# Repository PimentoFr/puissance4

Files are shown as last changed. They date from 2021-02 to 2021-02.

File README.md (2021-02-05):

# puissance4
Il s'agit d'un puissance 4 lumineux connecté et interractif par le chat Twitch

# Description

Ce projet a pour but de réaliser un écran LED basé sur des WS2812B (led addressable individuellement), piloté par un raspberry pi
afin d'ouvrir une surface de jeu pour le puissance 4. Le jeu sera connecté et intéractif avec le chat Twitch pour permettre
aux viewers et participants de chat de jouer leur partie.

Dans ce projet, l'arborescence est la suivante:
- `hardware` : L'ensemble des documents permettant la réalisation des cartes électroniques du projet
    - `panneau_led`: Contient le design de la carte électronique des dalles de LEDs.
    - `mainboard`: Carte principale permettant l'alimentation des Bucks 24V-5V pour les colonnes de la matrice de LEDs et la connection
    du Raspberry Pi.
- `software` : Bientôt.

# Logiciels

Les logiciels utilisées sont les suivants:
- hardware : [Kicad](https://kicad.org/download/)

# Electronique

## Panneau led

Les panneaux LEDs sont des panneaux de 90x90mm qui accueille chacun 9 LEDs de type WS2812B.
Elles sont tous chaînés de la manière suivante:

```
1 -> 2 -> 3
 <--------|
4 -> 5 -> 6
 <--------|
7 -> 8 -> 9
```

## Mainboard

Cette carte permet d'accueillir la source d'alimentation (Prise Power Jack 24V 4A) et de la répartir sur 7 borniers afin d'y brancher 7 convertisseurs DC/DC Buck pour alimenter chacun des 7 colonnes de la matrice de LEDs.
A cela, un support femelle 2x20 pins permet de connnecter un
Raspberry Pi afin d'assurer l'intelligence et le pilotage de ce
panneau LEDs. Un level shifter 3.3V->5V permet d'assurer l'adaptation de niveau logique entre la commande émise par le
Raspberry Pi et les WS2812B.

Plusieurs connecteurs supplémentaires permettent de brancher
d'autres périphériques au besoin en I2C/SPI/UART.

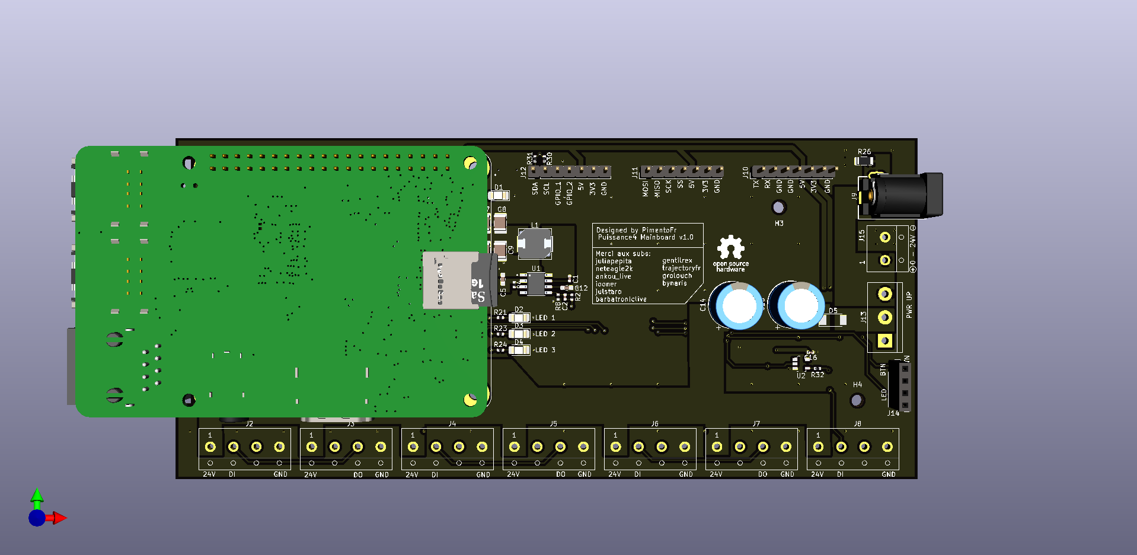
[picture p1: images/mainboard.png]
Mainboard

# Licence

Le projet est open-source. Tout le monde peut l'utiliser en laissant la référence à son auteur.

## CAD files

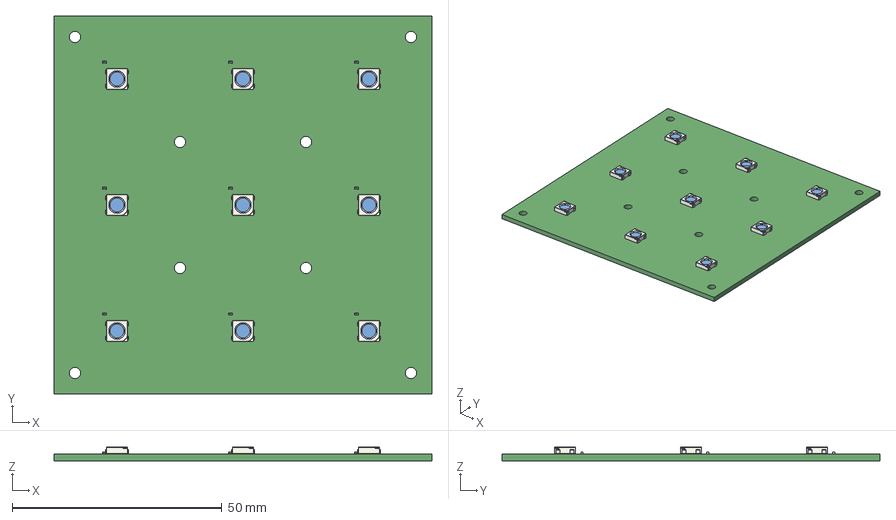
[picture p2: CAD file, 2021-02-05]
hardware/panneau_led/panneau led.step
90.0 x 90.0 x 3.25 mm

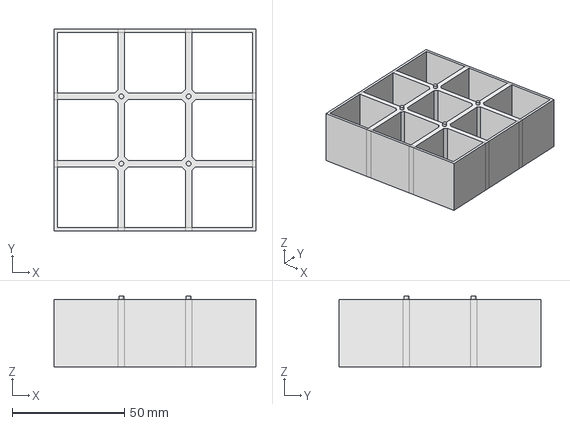
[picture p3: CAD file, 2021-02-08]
mecanics/separator_led.FCStd
90.0 x 90.0 x 31.6 mm

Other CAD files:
mecanics/separator_led.stl

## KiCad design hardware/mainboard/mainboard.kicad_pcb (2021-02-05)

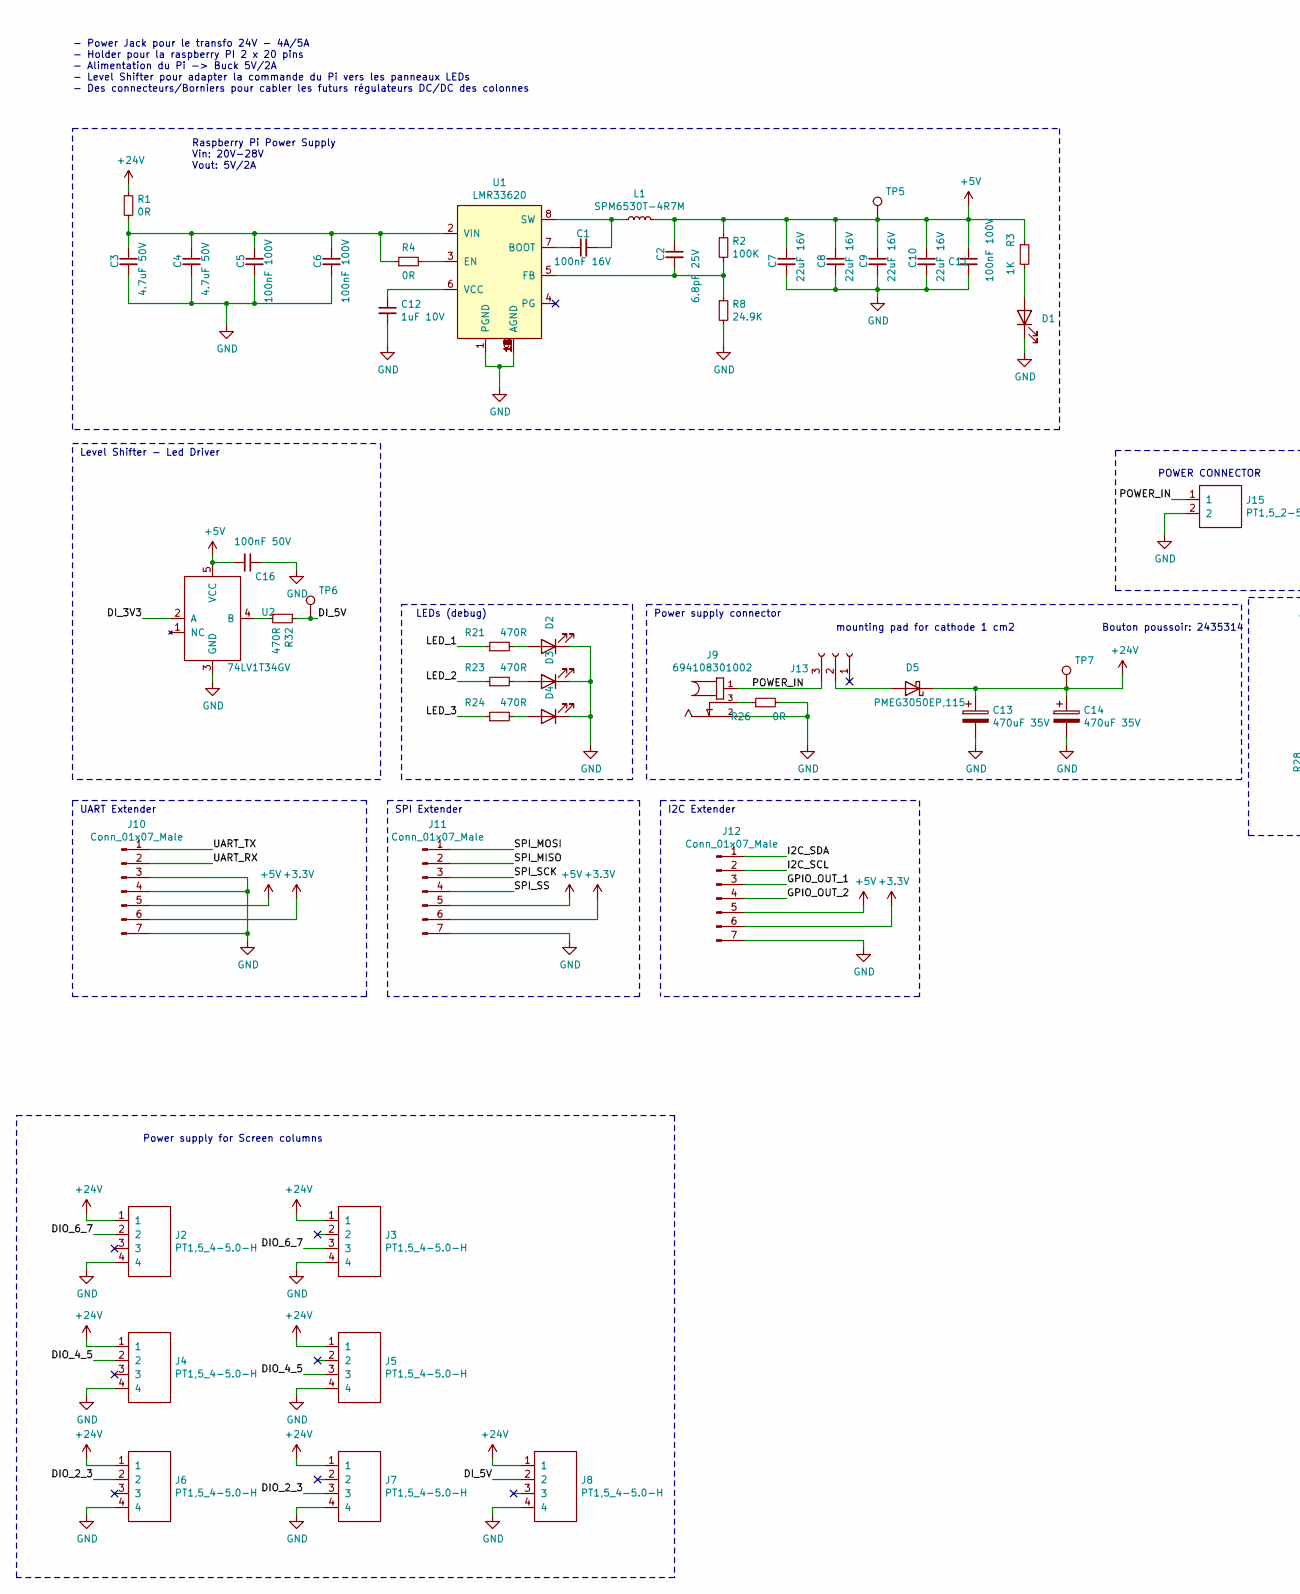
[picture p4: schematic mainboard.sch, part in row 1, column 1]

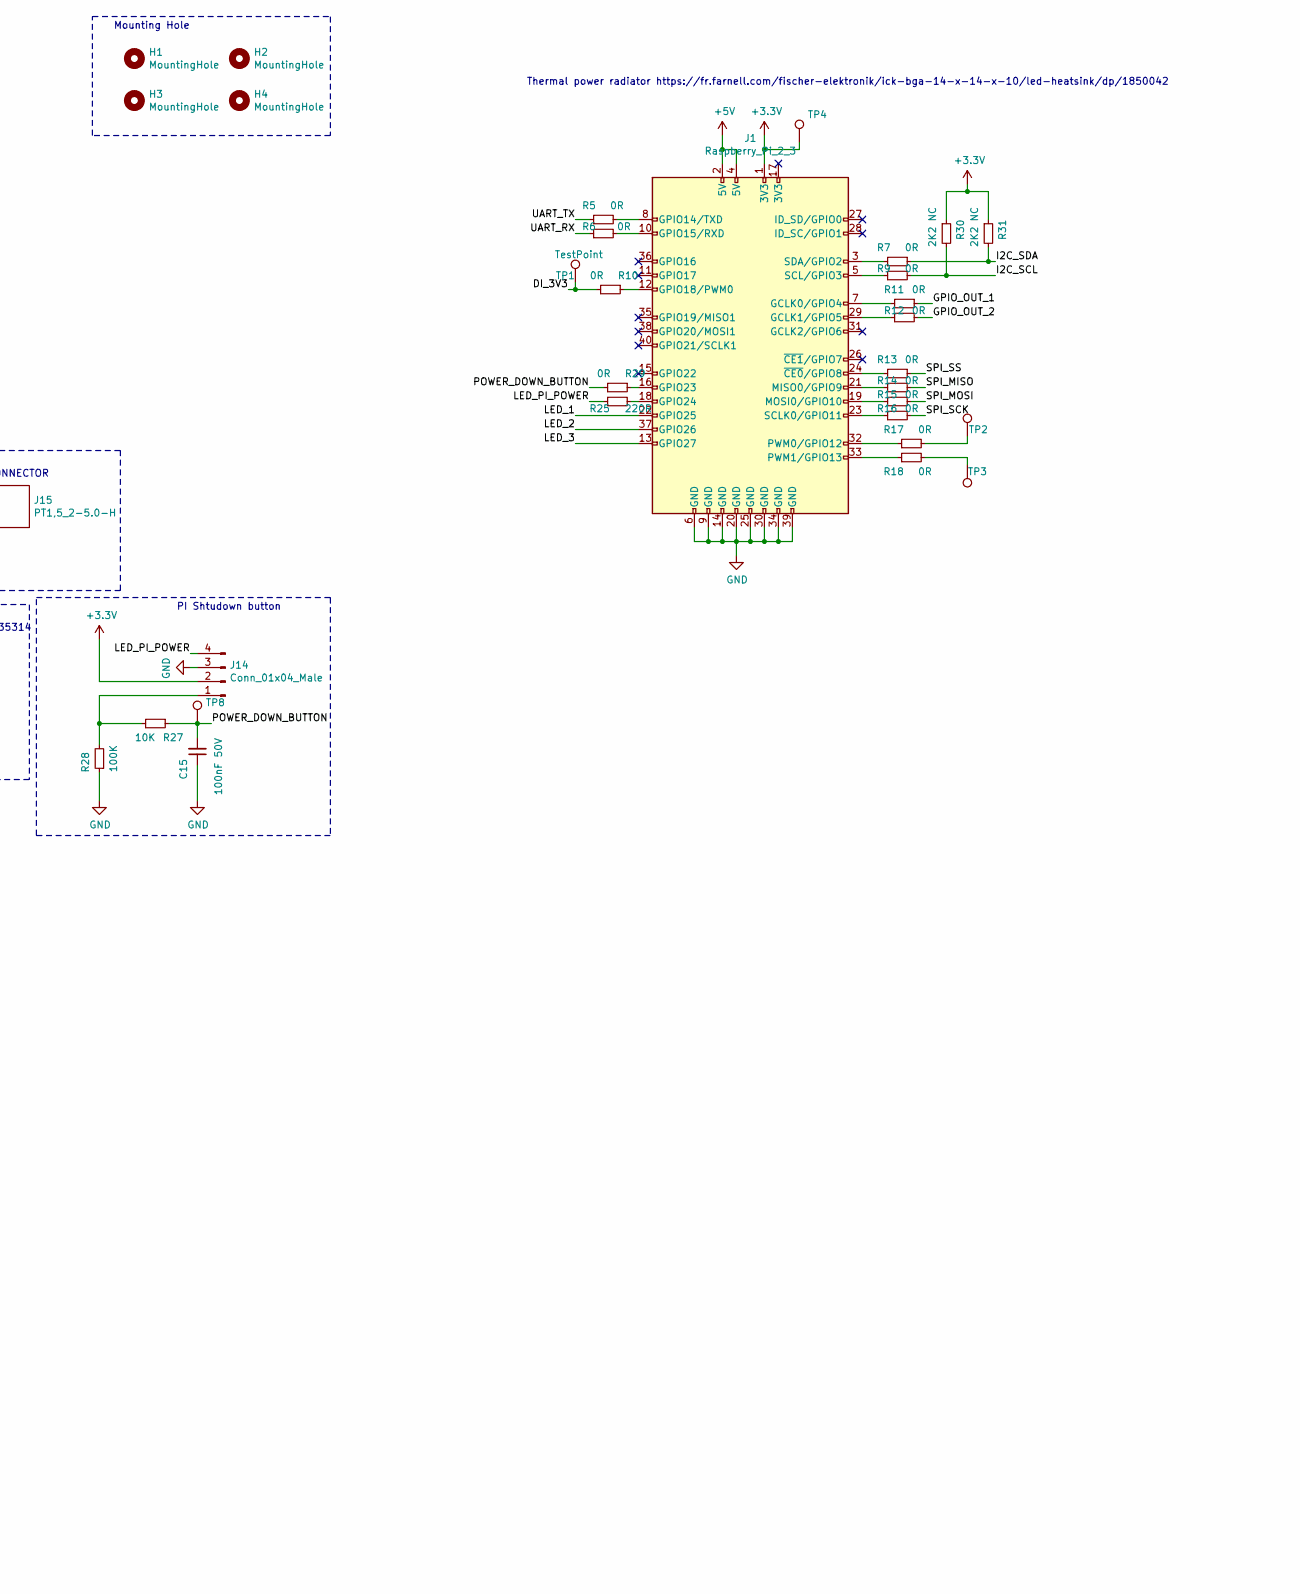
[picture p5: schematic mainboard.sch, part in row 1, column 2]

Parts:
C1: 100nF 16V; C_0402_1005Metric; farnell 2627345
C2: 6.8pF 25V; C_0402_1005Metric; farnell 2781440
C3: 4.7uF 50V; C_1206_3216Metric_Pad1.42x1.75mm_HandSolder; farnell 1735545
C4: 4.7uF 50V; C_1206_3216Metric_Pad1.42x1.75mm_HandSolder
C5, C6, C11: 100nF 100V; C_0603_1608Metric_Pad1.05x0.95mm_HandSolder; farnell 1828921
C7, C8, C9, C10: 22uF 16V; C_1210_3225Metric_Pad1.42x2.65mm_HandSolder; farnell 2112725
C12: 1uF 10V; C_0603_1608Metric_Pad1.05x0.95mm_HandSolder; farnell 9227776
C13, C14: 470uF 35V; CP_Radial_D10.0mm_P5.00mm; farnell 2805546
C15, C16: 100nF 50V; C_0402_1005Metric
D1, D2, D3, D4: MCL-S250GC; LED_1206_3216Metric_Pad1.42x1.75mm_HandSolder; farnell 1581232
D5: PMEG3050EP,115; D_SOD-128; farnell 1829197
H1, H2, H3, H4: MountingHole; MountingHole_2.5mm
J1: Raspberry_Pi_2_3; MODULE_RASPBERRY_PI_3_MODEL_B+_REVERSE
J2, J3, J4, J5, J6, J7, J8: PT1,5_4-5.0-H; PT1,5-4-5.0-H; farnell 1793677
J9: 694108301002; PART-NUMBER 694108301002; farnell 2472153
J10, J11: Conn_01x07_Male; PinHeader_1x07_P2.54mm_Vertical
J12: Conn_01x07_Male; PinHeader_1x07_P2.54mm_Vertical; farnell 2847167
J13: Conn_01x03_Female; TerminalBlock_bornier-3_P5.08mm
J14: Conn_01x04_Male; PinSocket_1x04_P2.54mm_Vertical
J15: PT1,5_2-5.0-H; PT1,5-2-5.0-H
L1: SPM6530T-4R7M; SPM6530T; farnell 2215613
R1: 0R; R_0805_2012Metric_Pad1.15x1.40mm_HandSolder
R2, R28: 100K; R_0402_1005Metric
R3: 1K; R_0402_1005Metric
R4, R5, R6, R7, R9, R10, R11, R12, R13, R14, R15, R16, R17, R18, R29: 0R; R_0402_1005Metric
R8: 24.9K; R_0402_1005Metric
R21, R23, R24, R32: 470R; R_0402_1005Metric
R25: 220R; R_0402_1005Metric
R26: 0R; R_1206_3216Metric
R27: 10K; R_0402_1005Metric
R30, R31: 2K2 NC; R_0402_1005Metric
TP1, TP2, TP3, TP4, TP5, TP6, TP7, TP8: TestPoint; TestPoint_Pad_D1.0mm
U1: LMR33620; 8pin-HSOIC; farnell 3007264
U2: 74LV1T34GV; SOT-753; farnell 3485601

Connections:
+3V3: J1.1 (3V3), J10.6, J11.6, J12.6, J14.2, R30.1, R31.1, TP4.1
+5V: C2.1, C7.1, C8.1, C9.1, C10.1, C11.1, C16.2, J1.2 (5V), J1.4 (5V), J10.5, J11.5, J12.5, L1.2, R2.1, R3.1, TP5.1, U2.5 (VCC)
+24V: C13.1, C14.1, D5.1 (K), J2.1, J3.1, J4.1, J5.1, J6.1, J7.1, J8.1, R1.1, TP7.1
/DIO_2_3: J6.2, J7.3
/DIO_4_5: J4.2, J5.3
/DIO_6_7: J2.2, J3.3
/DI_3V3: R10.2, TP1.1, U2.2 (A)
/DI_5V: J8.2, R32.1, TP6.1
/GPIO_OUT_1: J12.3, R11.1
/GPIO_OUT_2: J12.4, R12.1
/I2C_SCL: J12.2, R9.1, R30.2
/I2C_SDA: J12.1, R7.1, R31.2
/LED_1: J1.22 (GPIO25), R21.1
/LED_2: J1.37 (GPIO26), R23.1
/LED_3: J1.13 (GPIO27), R24.1
/LED_PI_POWER: J14.4, R25.1
/POWER_DOWN_BUTTON: C15.2, R27.1, R29.2, TP8.1
/POWER_IN: J9.1, J13.3, J15.1
/SPI_MISO: J11.2, R14.1
/SPI_MOSI: J11.1, R15.1
/SPI_SCK: J11.3, R16.1
/SPI_SS: J11.4, R13.1
/UART_RX: J10.2, R6.1
/UART_TX: J10.1, R5.1
GND: C3.2, C4.2, C5.2, C6.2, C7.2, C8.2, C9.2, C10.2, C11.2, C12.2, C13.2, C14.2, C15.1, C16.1, D1.1 (K), D2.1 (K), D3.1 (K), D4.1 (K), J1.6 (GND), J1.9 (GND), J1.14 (GND), J1.20 (GND), J1.25 (GND), J1.30 (GND), J1.34 (GND), J1.39 (GND), J2.4, J3.4, J4.4, J5.4, J6.4, J7.4, J8.4, J9.2, J10.3, J10.4, J10.7, J11.7, J12.7, J14.3, J15.2, R8.2, R26.2, R28.1, U1.1 (PGND), U1.9 (AGND), U1.10 (AGND), U1.11 (AGND), U1.12 (AGND), U1.13 (AGND), U1.14 (AGND), U1.15 (AGND), U1.16 (AGND), U1.17 (AGND), U2.3 (GND)
unnamed: C1.1, U1.7 (BOOT)
unnamed: C1.2, L1.1, U1.8 (SW)
unnamed: C2.2, R2.2, R8.1, U1.5 (FB)
unnamed: C3.1, C4.1, C5.1, C6.1, R1.2, R4.1, U1.2 (VIN)
unnamed: C12.1, U1.6 (VCC)
unnamed: D1.2 (A), R3.2
unnamed: D2.2 (A), R21.2
unnamed: D3.2 (A), R23.2
unnamed: D4.2 (A), R24.2
unnamed: D5.2 (A), J13.2
unnamed: J1.3 (SDA/GPIO2), R7.2
unnamed: J1.5 (SCL/GPIO3), R9.2
unnamed: J1.7 (GCLK0/GPIO4), R11.2
unnamed: J1.8 (GPIO14/TXD), R5.2
unnamed: J1.10 (GPIO15/RXD), R6.2
unnamed: J1.12 (GPIO18/PWM0), R10.1
unnamed: J1.16 (GPIO23), R29.1
unnamed: J1.18 (GPIO24), R25.2
unnamed: J1.19 (MOSI0/GPIO10), R15.2
unnamed: J1.21 (MISO0/GPIO9), R14.2
unnamed: J1.23 (SCLK0/GPIO11), R16.2
unnamed: J1.24 (~CE0~/GPIO8), R13.2
unnamed: J1.29 (GCLK1/GPIO5), R12.2
unnamed: J1.32 (PWM0/GPIO12), R17.1
unnamed: J1.33 (PWM1/GPIO13), R18.1
unnamed: J9.3, R26.1
unnamed: J14.1, R27.2, R28.2
unnamed: R4.2, U1.3 (EN)
unnamed: R17.2, TP2.1
unnamed: R18.2, TP3.1
unnamed: R32.2, U2.4 (B)

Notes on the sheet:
- Power Jack pour le transfo 24V - 4A/5A - Holder pour la raspberry PI 2 x 20 pins - Alimentation du Pi -> Buck 5V/2A - Level Shifter pour adapter la commande du Pi vers les panneaux LEDs - Des connecteurs/Borniers pour cabler les futurs régulateurs DC/DC des colonnes
Raspberry Pi Power Supply Vin: 20V-28V Vout: 5V/2A
Power supply connector
Level Shifter - Led Driver
Power supply for Screen columns
LEDs (debug)
UART Extender
SPI Extender
I2C Extender
mounting pad for cathode 1 cm2
Bouton poussoir: 2435314
POWER CONNECTOR
PI Shtudown button
Mounting Hole
Thermal power radiator https://fr.farnell.com/fischer-elektronik/ick-bga-14-x-14-x-10/led-heatsink/dp/1850042

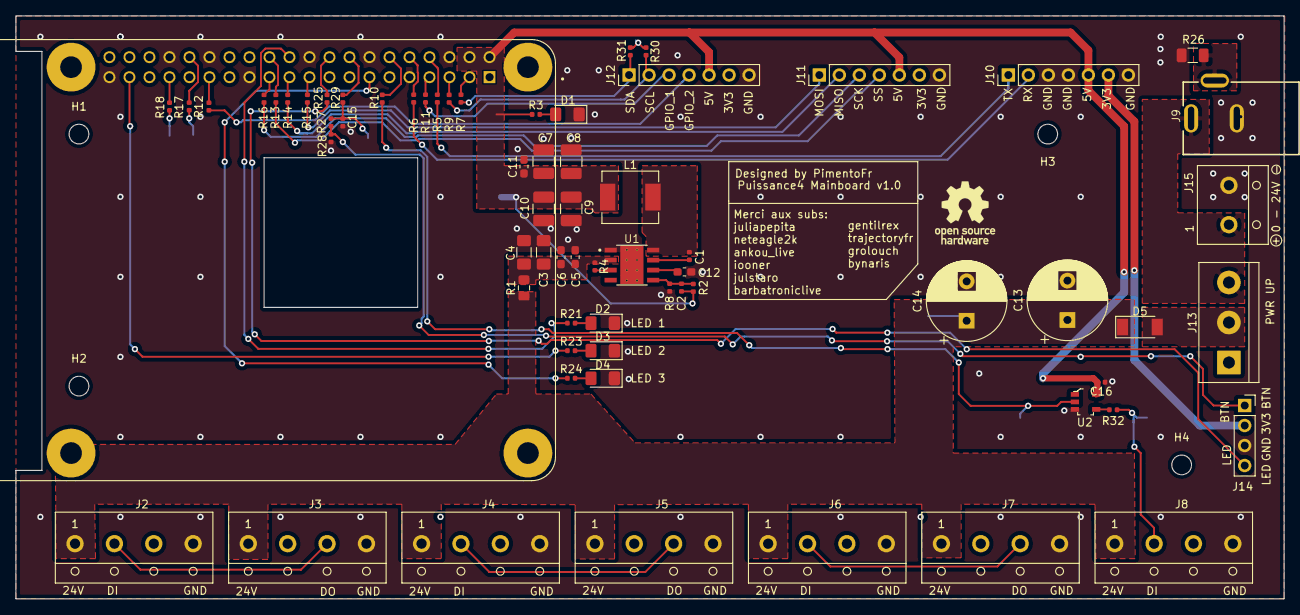
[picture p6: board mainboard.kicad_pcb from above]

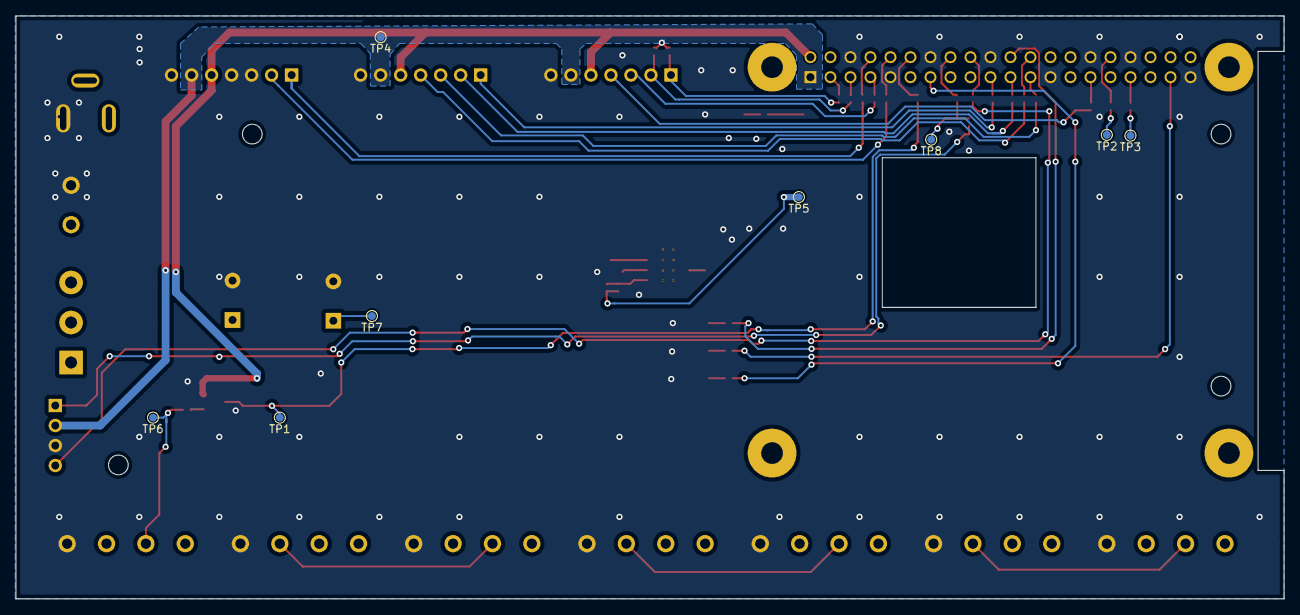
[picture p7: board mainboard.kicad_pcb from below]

Board: 2 copper layers, 161.0 x 74.0 mm, 80 parts (8 on the bottom side), 56 nets.

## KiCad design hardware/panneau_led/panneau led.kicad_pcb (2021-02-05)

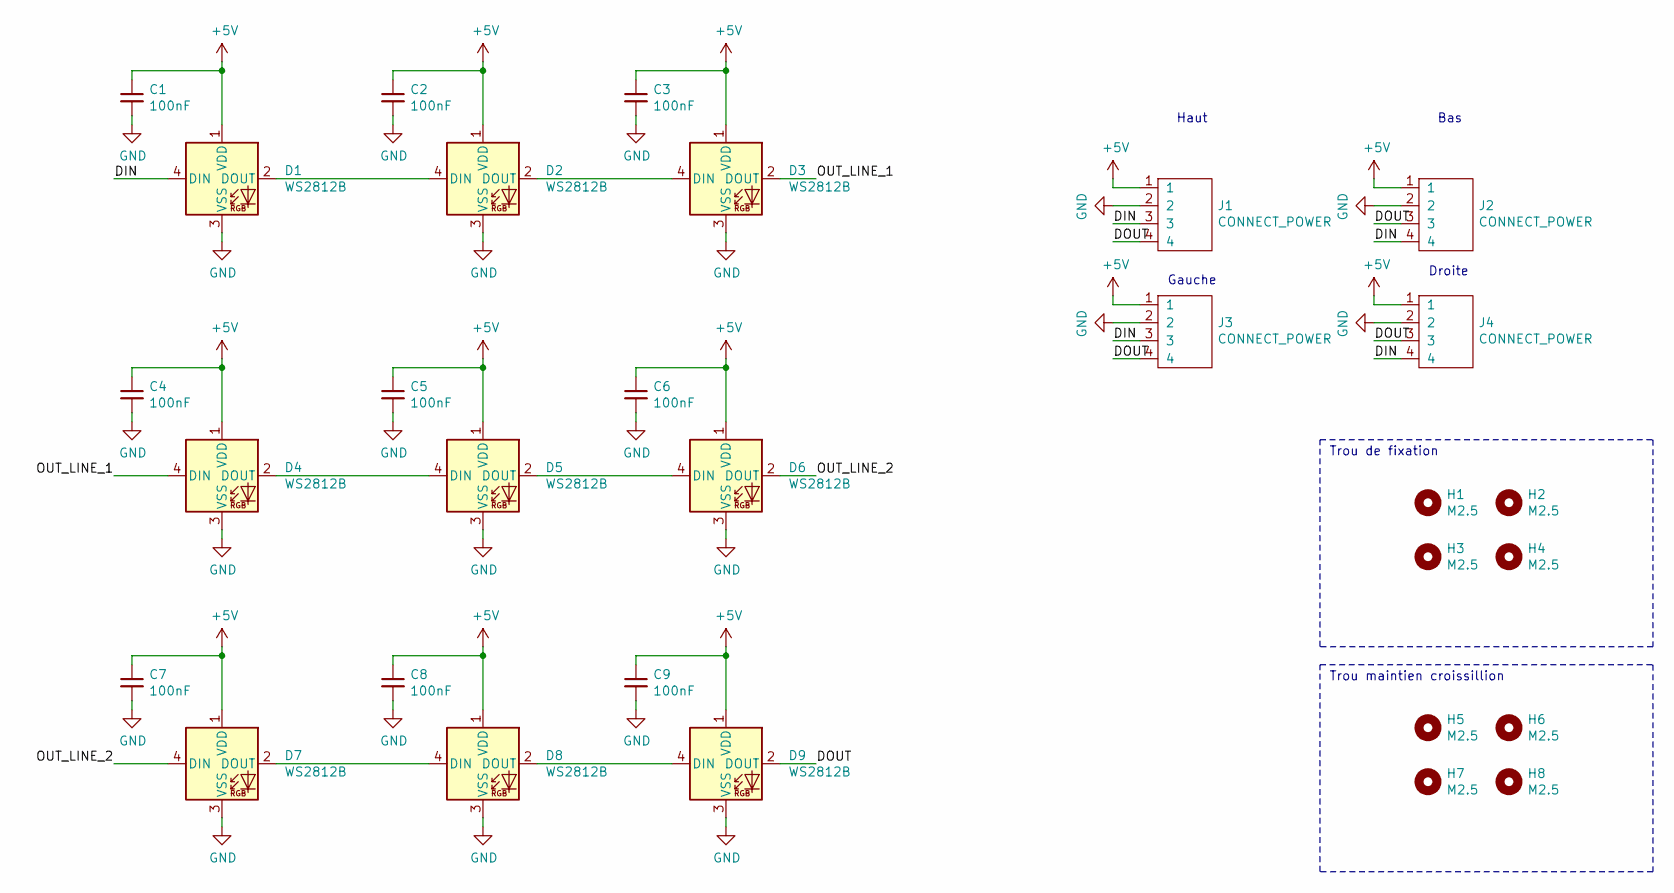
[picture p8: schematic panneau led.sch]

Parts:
C1, C2, C3, C4, C5, C6, C7, C8, C9: 100nF; C_0402_1005Metric; lcsc C1525
D1, D2, D3, D4, D5, D6, D7, D8, D9: WS2812B; LED_WS2812B_PLCC4_5.0x5.0mm_P3.2mm; lcsc C114586
H1, H2, H3, H4, H5, H6, H7, H8: M2.5; MountingHole_2.7mm_M2.5; lcsc NA
J1, J2, J3, J4: CONNECT_POWER; lcsc NA

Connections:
+5V: C1.1, C2.1, C3.1, C4.1, C5.1, C6.1, C7.1, C8.1, C9.1, D1.1 (VDD), D2.1 (VDD), D3.1 (VDD), D4.1 (VDD), D5.1 (VDD), D6.1 (VDD), D7.1 (VDD), D8.1 (VDD), D9.1 (VDD), J1.1, J2.1, J3.1, J4.1
/DIN: D1.4 (DIN), J1.3, J2.4, J3.3, J4.4
/DOUT: D9.2 (DOUT), J1.4, J2.3, J3.4, J4.3
/OUT_LINE_1: D3.2 (DOUT), D4.4 (DIN)
/OUT_LINE_2: D6.2 (DOUT), D7.4 (DIN)
GND: C1.2, C2.2, C3.2, C4.2, C5.2, C6.2, C7.2, C8.2, C9.2, D1.3 (VSS), D2.3 (VSS), D3.3 (VSS), D4.3 (VSS), D5.3 (VSS), D6.3 (VSS), D7.3 (VSS), D8.3 (VSS), D9.3 (VSS), J1.2, J2.2, J3.2, J4.2
unnamed: D1.2 (DOUT), D2.4 (DIN)
unnamed: D2.2 (DOUT), D3.4 (DIN)
unnamed: D4.2 (DOUT), D5.4 (DIN)
unnamed: D5.2 (DOUT), D6.4 (DIN)
unnamed: D7.2 (DOUT), D8.4 (DIN)
unnamed: D8.2 (DOUT), D9.4 (DIN)

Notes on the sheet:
Haut
Bas
Gauche
Droite
Trou de fixation
Trou maintien croissillion

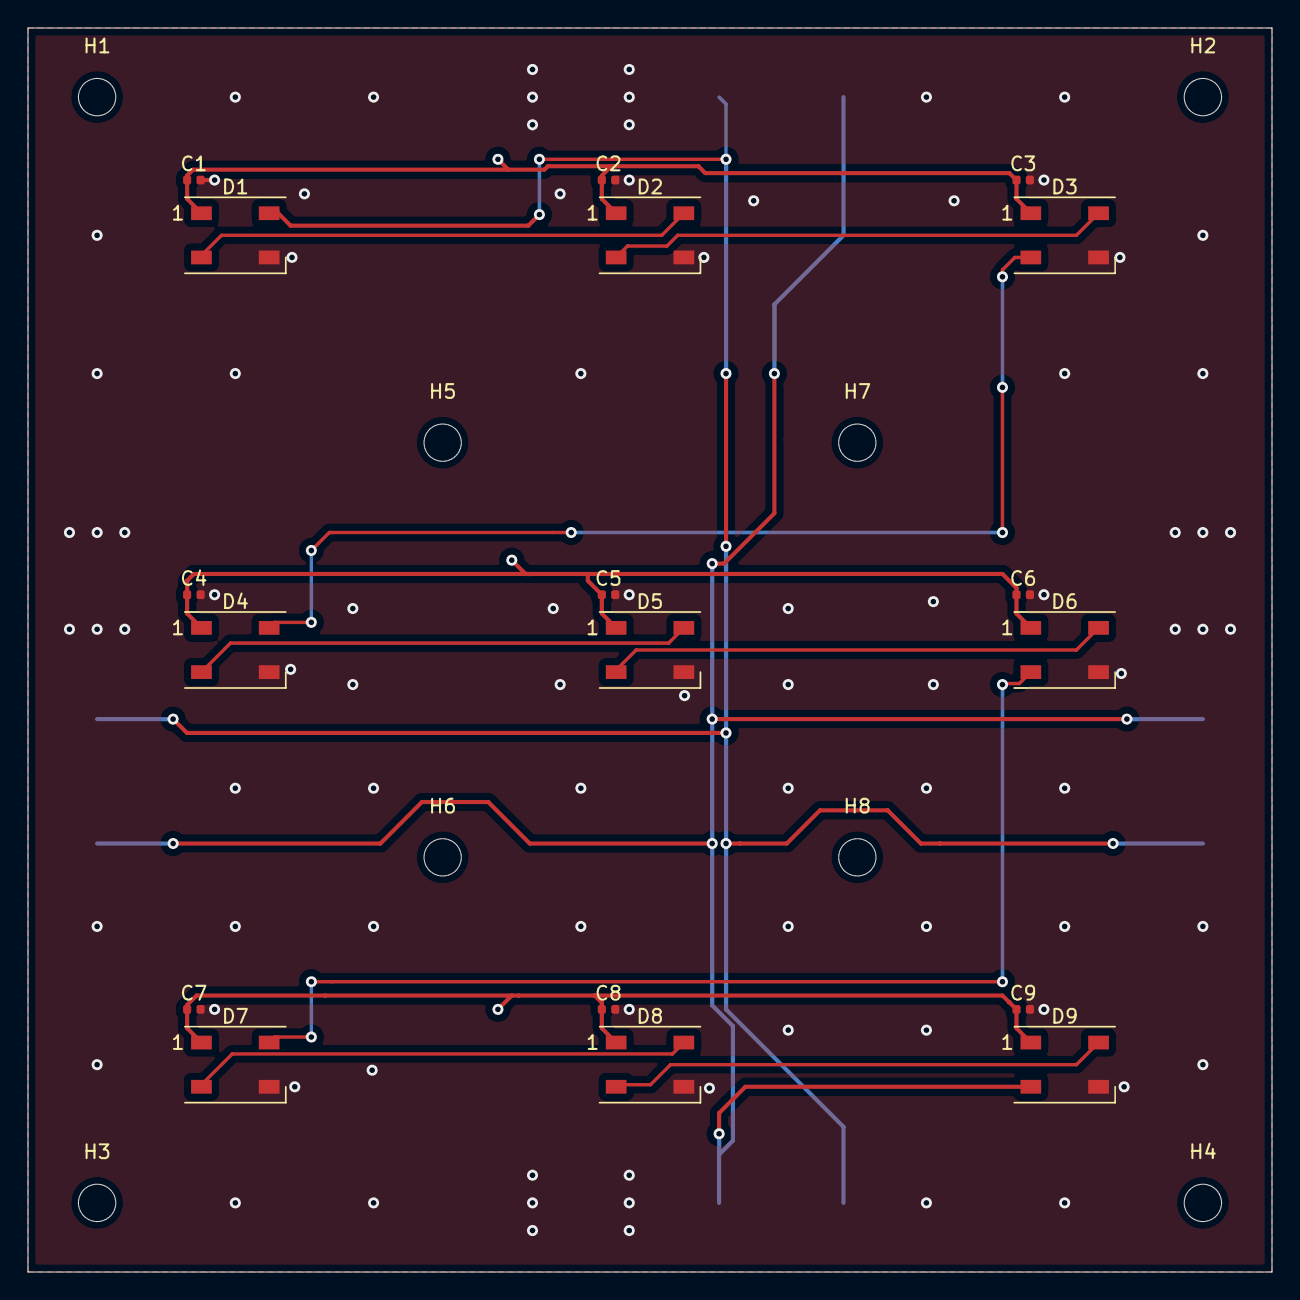
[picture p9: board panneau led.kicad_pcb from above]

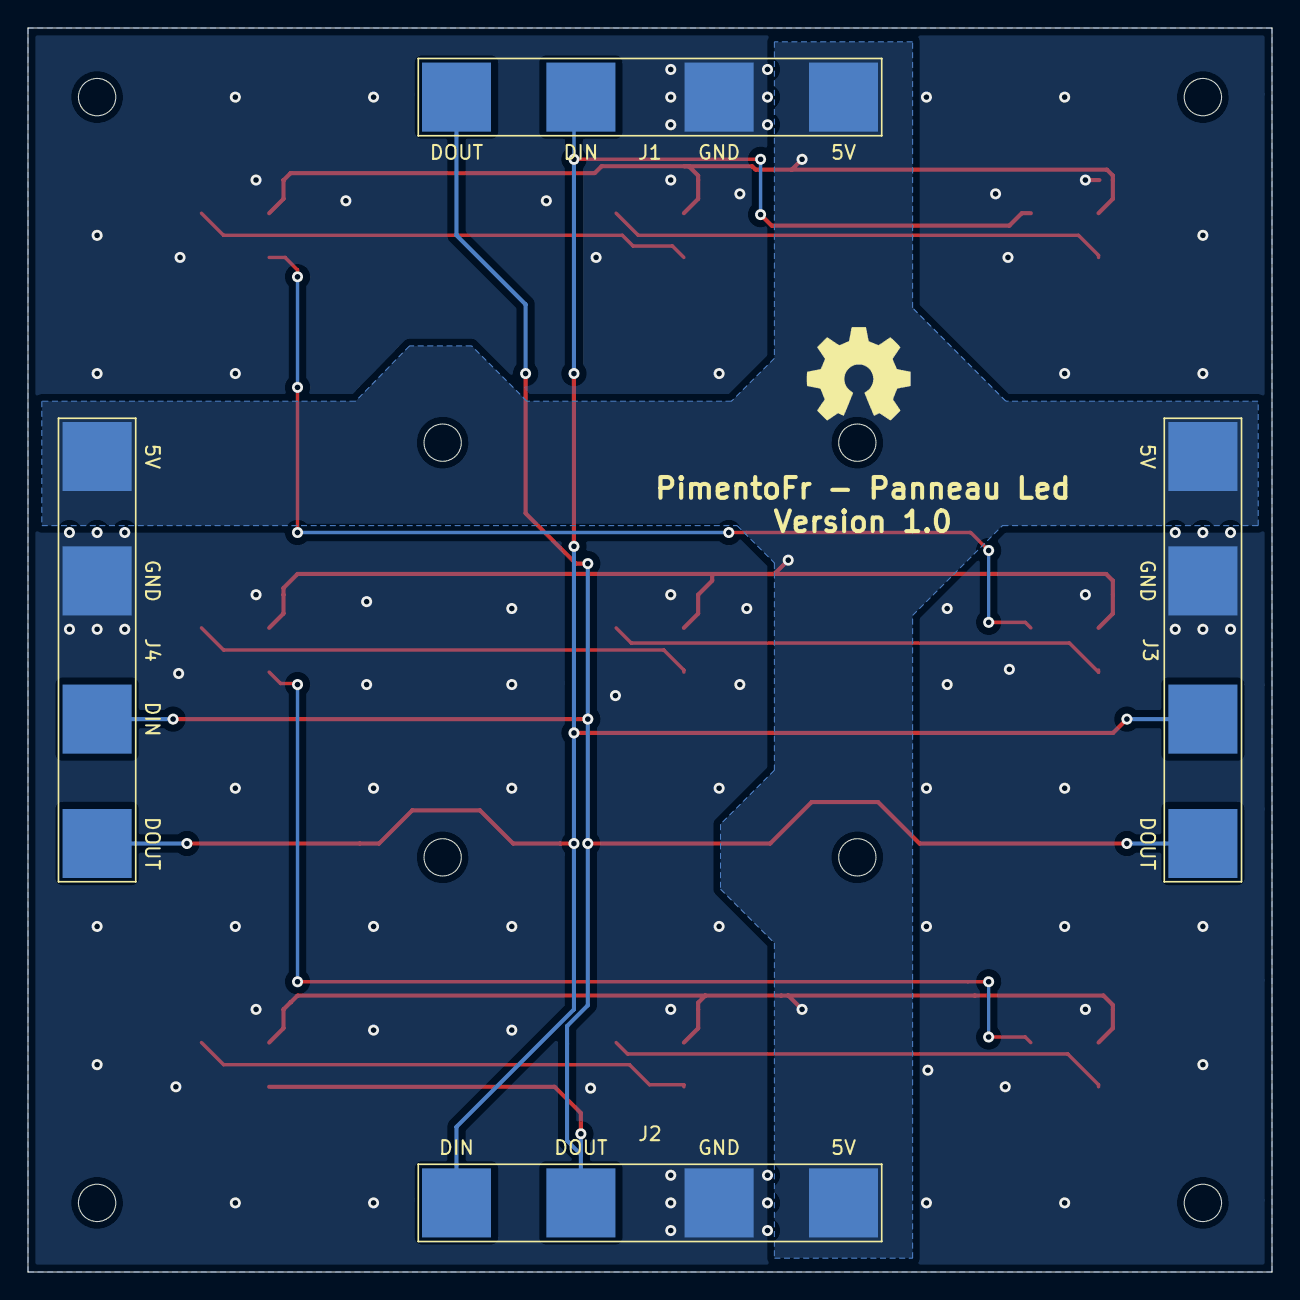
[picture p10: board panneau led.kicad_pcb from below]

Board: 2 copper layers, 90.0 x 90.0 mm, 30 parts (4 on the bottom side), 12 nets.

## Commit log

2021-02-05 feat: hw: add design files for the led board
    [panneau led.kicad_pcb, panneau led.sch, panneau led.step]
2021-02-05 doc: complete readme for the led panel board
2021-02-05 feat: hw: add design files for mainboard
    This board permit to control a matrix of 7x7 LED panels. This board should be powered up by a 24V 4A power supply.
    A 2x20 pins connectors can host a Raspberry Pi.
    [mainboard.kicad_pcb, mainboard.sch]
2021-02-08 wip: feat: meca: add separator for led panels
    This element is designed with FreeCad
    [separator_led.FCStd, separator_led.stl]
